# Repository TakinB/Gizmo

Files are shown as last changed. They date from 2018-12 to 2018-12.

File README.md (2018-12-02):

# Deck Tape 

<p align="center">
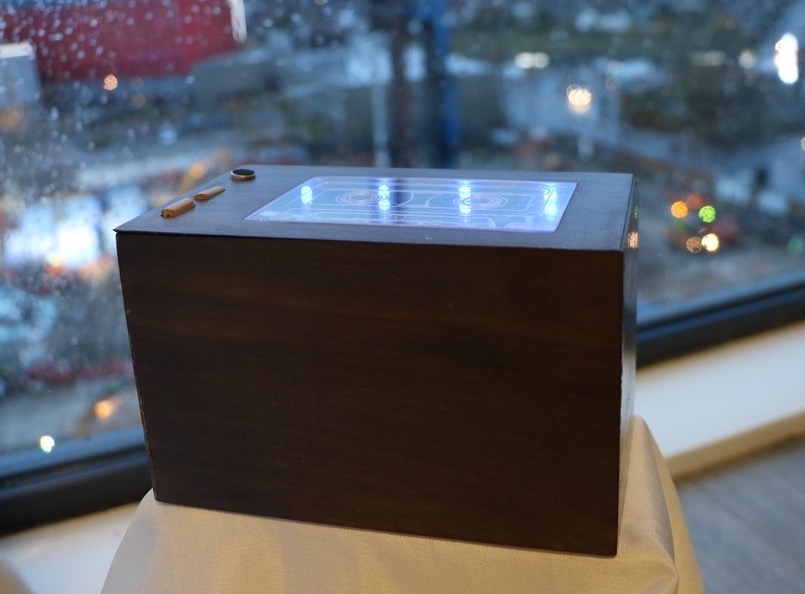
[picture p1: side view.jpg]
  
</p>

Deck Tape is a tribute to cassette players. It's an audio visualizer that integrates sound, color, and touch. 
An Arduino Uno board is used to control LED lights as well as the speed and direction of a DC motor based on the volume of the environment sounds and music.

A magnet is mounted on top of each DC motor which creates patterns in iron filings on the box top surface.

<p align="center">
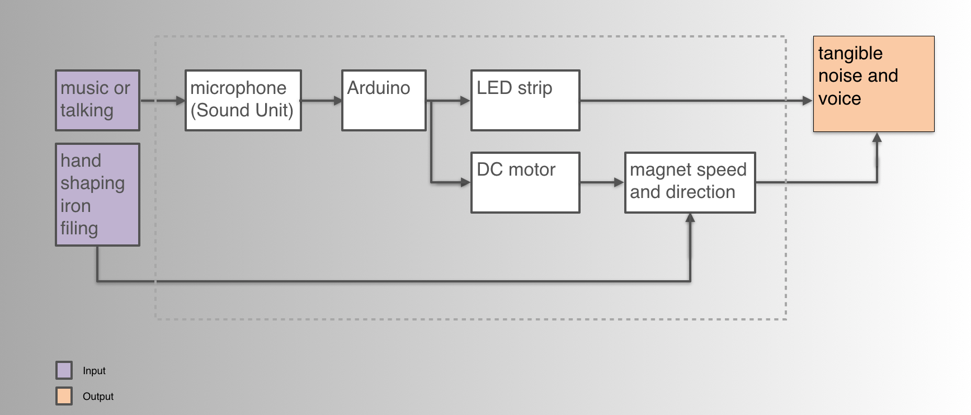
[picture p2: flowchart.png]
  
</p>

**Why magnets?** 
>Cassette players use an electronic magnet to permanently change the orientation of magnetic oxide materials on the cassette tapes.

**Why cassettes?**  
>When I look back, I remember every cassette tape that I owned and my emotions when listening to them. However, it wasn't the case with my digital album collections. So I started with the question of: How can we bring the physical interaction that we had with cassette tapes into the modern way of listening to music?

In order to recreate the physical interaction with a cassette player, push buttons in Deck Tape is made with the same metallic latches that cassette players use. In other words, when you press buttons, you'll hear the same nostalgic click of old cassette players.
Also, users can change the patterns being shaped by the magnet by playing with the iron filings. In addition, LED colors and intensities change based on the historical volume of the song.

<p align="center">
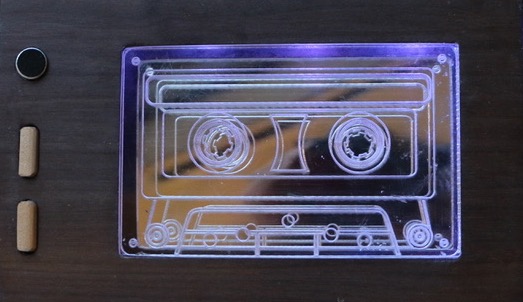
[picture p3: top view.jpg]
  
</p>

## Getting Started
**Hardware:**
You will need the following in order to build the hardware:

 1. ring magnets (2) 
 2. DC motors (2)
 3. mirror acrylic 
 4. clear acrylic 
 5. walnut tree wood sheet
 6.  sound unit 
 7. Arduino Uno 
 8. power supply 
 9. LED strip Neo Pixel 
 10. L293D motor driver

**Software:**
You will need the following libraries installed for Arduino:
[Adafruit's NeoPixel library](https://github.com/adafruit/Adafruit_NeoPixel)

## Schematics
Please refer to the schematics folder on how to wire up the board with motors, sound module, and LED strip.

## Licenses

 - Bahareh Saboktakin, Royal College of Art, 27/11/2018
 - SparkFun Addressable RGB LED Sound and Music Visualizer Tutorial Arduino Code by Michael Bartlett date: 2/7/16 and 27/11/18 license: Creative Commons Attribution-ShareAlike 4.0 (CC BY-SA 4.0)

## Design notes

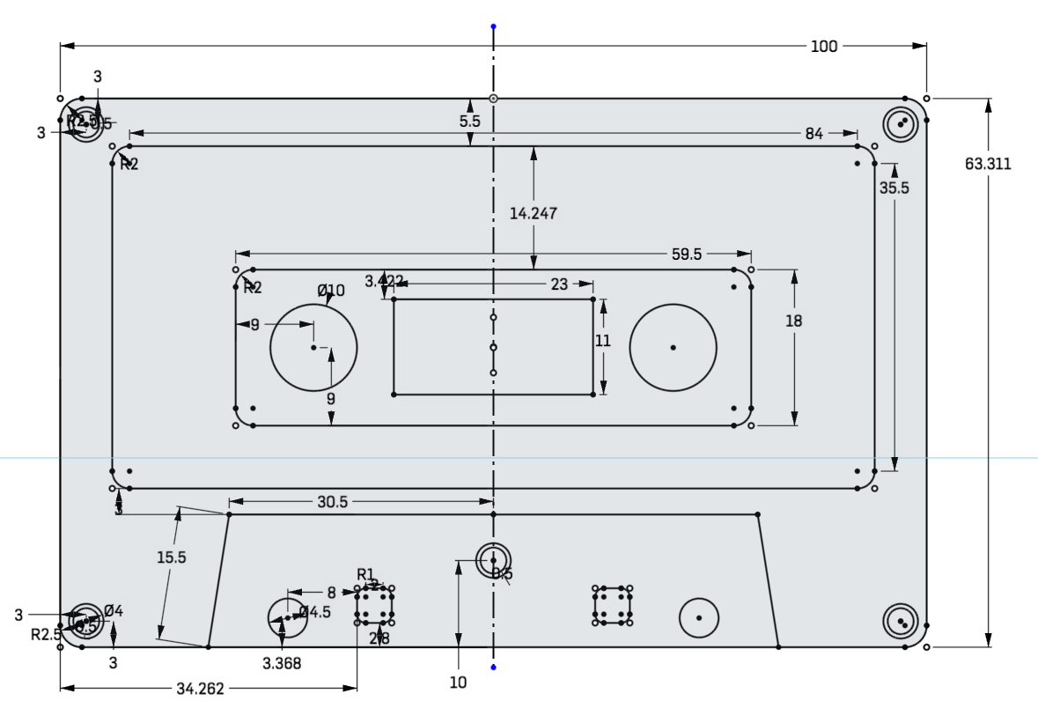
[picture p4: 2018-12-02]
Laser cutter files/cassette tape dimensions.png

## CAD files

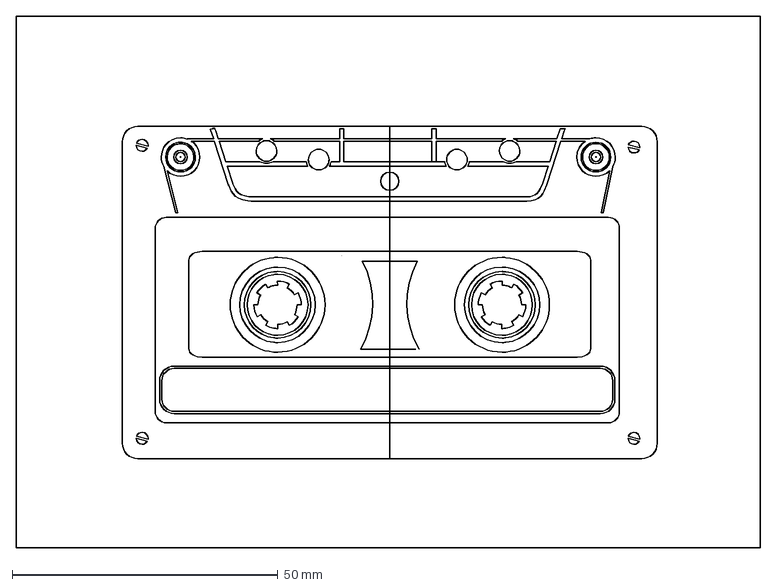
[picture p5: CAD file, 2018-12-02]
Laser cutter files/cassette tape top etching.dxf
140.0 x 100.0 mm

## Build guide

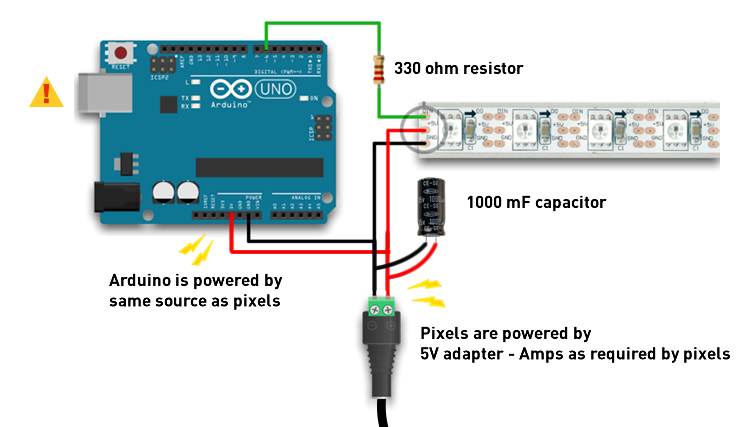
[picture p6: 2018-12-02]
Schematics/LED strip wiring - from adafruit.png

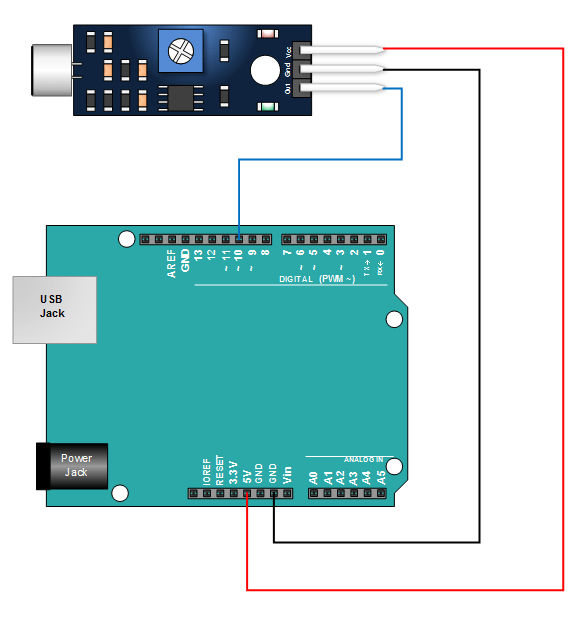
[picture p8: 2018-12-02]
Schematics/sound module wiring - from Henrys bench.png

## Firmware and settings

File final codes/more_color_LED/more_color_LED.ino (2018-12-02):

/* SparkFun Addressable RGB LED Sound and Music Visualizer Tutorial Arduino Code
 * by: Michael Bartlett
 * and: Bahareh Saboktakin
 * Royal College of Art
 * SparkFun Electronics
 * date: 2/7/16 and 27/11/18
 * license: Creative Commons Attribution-ShareAlike 4.0 (CC BY-SA 4.0)
 * Do whatever you'd like with this code, use it for any purpose.
 * Please attribute and keep this license.
*/

//Libraries
#include <Adafruit_NeoPixel.h>  //Library to simplify interacting with the LED strand
#ifdef __AVR__
#include <avr/power.h>   //Includes the library for power reduction registers if your chip supports them. 
#endif                   //More info: http://www.nongnu.org/avr-libc/user-manual/group__avr__power.htlm


//Constants (change these as necessary)
#define LED_PIN    7 //Pin for the pixel strand. Can be analog or digital.
#define LED_TOTAL 20  //Change this to the number of LEDs in your strand.
#define LED_HALF  LED_TOTAL/2
#define VISUALS   6   //Change this accordingly if you add/remove a visual in the switch-case in Visualize()

#define AUDIO_PIN A0  //Pin for the envelope of the sound detector
#define KNOB_PIN  A1  //Pin for the trimpot 10K

//DC Motor 1
#define ENABLE1 5
#define DIRA1 3
#define DIRB1 4

//DC Motor 2
#define ENABLE2 10
#define DIRA2 8
#define DIRB2 9

//////////<Globals>
//  These values either need to be remembered from the last pass of loop() or
//  need to be accessed by several functions in one pass, so they need to be global.

Adafruit_NeoPixel strand = Adafruit_NeoPixel(LED_TOTAL, LED_PIN, NEO_GRB + NEO_KHZ800);  //LED strand objects

uint16_t gradient = 0; //Used to iterate and loop through each color palette gradually

//IMPORTANT:
//  This array holds the "threshold" of each color function (i.e. the largest number they take before repeating).
//  The values are in the same order as in ColorPalette()'s switch case (Rainbow() is first, etc). This is simply to
//  keep "gradient" from overflowing, the color functions themselves can take any positive value. For example, the
//  largest value Rainbow() takes before looping is 1529, so "gradient" should reset after 1529, as listed.
//     Make sure you add/remove values accordingly if you add/remove a color function in the switch-case in ColorPalette().

uint16_t thresholds[] = {1529, 1019, 764, 764, 764, 1274};

uint8_t palette = 0;  //Holds the current color palette.
uint8_t visual = 0;   //Holds the current visual being displayed.
uint8_t volume = 0;   //Holds the volume level read from the sound detector.
uint8_t last = 0;     //Holds the value of volume from the previous loop() pass.

float maxVol = 200;    //Holds the largest volume recorded thus far to proportionally adjust the visual's responsiveness.
float knob = 1023.0;  //Holds the percentage of how twisted the trimpot is. Used for adjusting the max brightness.
float avgBump = 0;    //Holds the "average" volume-change to trigger a "bump."
float avgVol = 0;     //Holds the "average" volume-level to proportionally adjust the visual experience.
float shuffleTime = 0;  //Holds how many seconds of runtime ago the last shuffle was (if shuffle mode is on).

////////////////////////////////////////////////////////////////////////////////////////////////////////////////
//NOTE: The reason "average" is quoted is because it is not a true mathematical average. This is because I have
//      found what I call a "sequenced average" is more successful in execution than a real average. The difference
//      is that the sequenced average doesn't use the pool of all values recorded thus far, but rather averages the
//      last average and the current value received (in sequence). Concretely:
//
//          True average: (1 + 2 + 3) / 3 = 2
//          Sequenced: (1 + 2) / 2 = 1.5 --> (1.5 + 3) / 2 = 2.25  (if 1, 2, 3 was the order the values were received)
//
//      All "averages" in the program operate this way. The difference is subtle, but the reason is that sequenced
//      averages are more adaptive to changes in the overall volume. In other words, if you went from loud to quiet,
//      the sequenced average is more likely to show an accurate and proportional adjustment more fluently.
////////////////////////////////////////////////////////////////////////////////////////////////////////////////

bool shuffle = false;  //Toggles shuffle mode.
bool bump = false;     //Used to pass if there was a "bump" in volume

//For Traffic() visual
int8_t pos[LED_TOTAL] = { -2};    //Stores a population of color "dots" to iterate across the LED strand.
uint8_t rgb[LED_TOTAL][3] = {0};  //Stores each dot's specific RGB values.

//For Snake() visual
bool left = false;  //Determines the direction of iteration. Recycled in PaletteDance()
int8_t dotPos = 0;  //Holds which LED in the strand the dot is positioned at. Recycled in most other visuals.
float timeBump = 0; //Holds the time (in runtime seconds) the last "bump" occurred.
float avgTime = 0;  //Holds the "average" amount of time between each "bump" (used for pacing the dot's movement).

//Motor Control variables
int maxDirTime = 1000; //Maximum delay time that motor rotates in same direction
int motor_dir_counter = 0;

//////////</Globals>


//////////<Standard Functions>

void setup() {    //Like it's named, this gets ran before any other function.

  //pinMode(A0,INPUT_PULLUP); //added initially for creating a switch from cassette player push buttons.

  pinMode(ENABLE1,OUTPUT);
  pinMode(DIRA1,OUTPUT);
  pinMode(DIRB1,OUTPUT);

  pinMode(ENABLE2,OUTPUT);
  pinMode(DIRA2,OUTPUT);
  pinMode(DIRB2,OUTPUT);
  
  Serial.begin(9600); //Sets data rate for serial data transmission.

  //Defines the buttons pins to be input.
  pinMode(BUTTON_1, INPUT); pinMode(BUTTON_2, INPUT); pinMode(BUTTON_3, INPUT);

  //Write a "HIGH" value to the button pins.
  digitalWrite(BUTTON_1, HIGH); digitalWrite(BUTTON_2, HIGH); digitalWrite(BUTTON_3, HIGH);

  strand.begin(); //Initialize the LED strand object.
  strand.show();  //Show a blank strand, just to get the LED's ready for use.
}


void loop() {  //This is where the magic happens. This loop produces each frame of the visual.

  volume = analogRead(AUDIO_PIN);       //Record the volume level from the sound detector
  knob = analogRead(KNOB_PIN) / 1023.0; //Record how far the trimpot is twisted
  
  // if (!  digitalRead(A0)){ // If switch is ON (cassette player play button is pressed) go ahead with LED lighting and pwm for controling motor
  
  //Sets a threshold for volume.
  //  In practice I've found noise can get up to 15, so if it's lower, the visual thinks it's silent.
  //  Also if the volume is less than average volume / 2 (essentially an average with 0), it's considered silent.
  if (volume < avgVol / 2.0 || volume < 15) volume = 0;

  else avgVol = (avgVol + volume) / 2.0; //If non-zeo, take an "average" of volumes.

  //If the current volume is larger than the loudest value recorded, overwrite
  if (volume > maxVol) maxVol = volume;

  //Check the Cycle* functions for specific instructions if you didn't include buttons in your design.
  ////////////////////////////////////////////////////////////////////////////////////////////////////
  CyclePalette();  //Changes palette for shuffle mode or button press.

  CycleVisual();   //Changes visualization for shuffle mode or button press.
  ////////////////////////////////////////////////////////////////////////////////////////////////////

  //This is where "gradient" is modulated to prevent overflow.
  if (gradient > thresholds[palette]) {
    gradient %= thresholds[palette] + 1;

    //Everytime a palette gets completed is a good time to readjust "maxVol," just in case
    //  the song gets quieter; we also don't want to lose brightness intensity permanently
    //  because of one stray loud sound.
    maxVol = (maxVol + volume) / 2.0;
  }

  //If there is a decent change in volume since the last pass, average it into "avgBump"
  if (volume - last > 10) avgBump = (avgBump + (volume - last)) / 2.0;

  //If there is a notable change in volume, trigger a "bump"
  //  avgbump is lowered just a little for comparing to make the visual slightly more sensitive to a beat.
  bump = (volume - last > avgBump * .9);  

  //If a "bump" is triggered, average the time between bumps
  if (bump) {
    avgTime = (((millis() / 1000.0) - timeBump) + avgTime) / 2.0;
    timeBump = millis() / 1000.0;
  }

  //Debugging serial prints
  Serial.println("max volume");
  Serial.println(maxVol);

  Serial.println("Mic value");
  Serial.println(volume);
  
  Visualize();   //Calls the appropriate visualization to be displayed with the globals as they are.

  ControlMotor();  //Controls directions of the DC motor based on whether we had a bump in the volume.
  
  gradient++;    //Increments gradient

  last = volume; //Records current volume for next pass

  delay(30);     //Paces visuals so they aren't too fast to be enjoyable
//}
  //else{ // Do this if the cassette player stop push button is pressed (switch off)
    //   digitalWrite(ENABLE1,0); //enable on
      // digitalWrite(ENABLE2,0); //enable on
    //}
}
//////////</Standard Functions>


//////////<Visual Functions>

//This function calls the appropriate visualization based on the value of "visual"
void Visualize() {
  switch (visual) {
    case 0: return Pulse();
    case 1: return PalettePulse();
    case 2: return Traffic();
    case 3: return Snake();
    case 4: return PaletteDance();
    case 5: return Glitter();
    case 6: return Paintball();
    default: return Pulse();
  }
}

//////////////////////////////////////////////////////////////////////////////////////////////////////////
//NOTE: The strand displays RGB values as a 32 bit unsigned integer (uint32_t), which is why ColorPalette()
//      and all associated color functions' return types are uint32_t. This value is a composite of 3
//      unsigned 8bit integer (uint8_t) values (0-255 for each of red, blue, and green). You'll notice the
//      function split() (listed below) is used to dissect these 8bit values from the 32-bit color value.
//////////////////////////////////////////////////////////////////////////////////////////////////////////


//This function calls the appropriate color palette based on "palette"
//  If a negative value is passed, returns the appropriate palette withe "gradient" passed.
//  Otherwise returns the color palette with the passed value (useful for fitting a whole palette on the strand).
uint32_t ColorPalette(float num) {
  switch (palette) {
    case 0: return (num < 0) ? Rainbow(gradient) : Rainbow(num);
    case 1: return (num < 0) ? Sunset(gradient) : Sunset(num);
    case 2: return (num < 0) ? Ocean(gradient) : Ocean(num);
    case 3: return (num < 0) ? PinaColada(gradient) : PinaColada(num);
    case 4: return (num < 0) ? Sulfur(gradient) : Sulfur(num);
    case 5: return (num < 0) ? NoGreen(gradient) : NoGreen(num);
    default: return Rainbow(gradient);
  }
}

///////////////////////////////////////////////////////////////////////////////////////////////////////////////
//NOTE: All of these visualizations feature some aspect that affects brightness based on the volume relative to
//      maxVol, so that louder = brighter. Initially, I did simple proportions (volume/maxvol), but I found this
//      to be visually indistinct. I then tried an exponential method (raising the value to the power of
//      volume/maxvol). While this was more visually satisfying, I've opted for a balance between the two. You'll
//      notice something like pow(volume/maxVol, 2.0) in the functions below. This simply squares the ratio of
//      volume to maxVol to get a more exponential curve, but not as exaggerated as an actual exponential curve.
//      In essence, this makes louder volumes brighter, and lower volumes dimmer, to be more visually distinct.
///////////////////////////////////////////////////////////////////////////////////////////////////////////////


//PULSE
//Pulse from center of the strand
void Pulse() {

  fade(0.75);   //Listed below, this function simply dims the colors a little bit each pass of loop()

  //Advances the palette to the next noticeable color if there is a "bump"
  if (bump) gradient += thresholds[palette] / 24;

  //If it's silent, we want the fade effect to take over, hence this if-statement
  if (volume > 0) {
    uint32_t col = ColorPalette(-1); //Our retrieved 32-bit color

    //These variables determine where to start and end the pulse since it starts from the middle of the strand.
    //  The quantities are stored in variables so they only have to be computed once (plus we use them in the loop).
    int start = LED_HALF - (LED_HALF * (volume / maxVol));
    int finish = LED_HALF + (LED_HALF * (volume / maxVol)) + strand.numPixels() % 2;
    //Listed above, LED_HALF is simply half the number of LEDs on your strand. ↑ this part adjusts for an odd quantity.

    for (int i = start; i < finish; i++) {

      //"damp" creates the fade effect of being dimmer the farther the pixel is from the center of the strand.
      //  It returns a value between 0 and 1 that peaks at 1 at the center of the strand and 0 at the ends.
      float damp = sin((i - start) * PI / float(finish - start));

      //Squaring damp creates more distinctive brightness.
      damp = pow(damp, 2.0);

      //Fetch the color at the current pixel so we can see if it's dim enough to overwrite.
      uint32_t col2 = strand.getPixelColor(i);

      //Takes advantage of one for loop to do the following:
      // Appropriatley adjust the brightness of this pixel using location, volume, and "knob"
      // Take the average RGB value of the intended color and the existing color, for comparison
      uint8_t colors[3];
      float avgCol = 0, avgCol2 = 0;
      for (int k = 0; k < 3; k++) {
        colors[k] = split(col, k) * damp * knob * pow(volume / maxVol, 2);
        avgCol += colors[k];
        avgCol2 += split(col2, k);
      }
      avgCol /= 3.0, avgCol2 /= 3.0;

      //Compare the average colors as "brightness". Only overwrite dim colors so the fade effect is more apparent.
      if (avgCol > avgCol2) strand.setPixelColor(i, strand.Color(colors[0], colors[1], colors[2]));
    }
  }
  //This command actually shows the lights. If you make a new visualization, don't forget this!
  strand.show();
}


//PALETTEPULSE
//Same as Pulse(), but colored the entire pallet instead of one solid color
void PalettePulse() {
  fade(0.75);
  if (bump) gradient += thresholds[palette] / 24;
  if (volume > 0) {
    int start = LED_HALF - (LED_HALF * (volume / maxVol));
    int finish = LED_HALF + (LED_HALF * (volume / maxVol)) + strand.numPixels() % 2;
    for (int i = start; i < finish; i++) {
      float damp = sin((i - start) * PI / float(finish - start));
      damp = pow(damp, 2.0);

      //This is the only difference from Pulse(). The color for each pixel isn't the same, but rather the
      //  entire gradient fitted to the spread of the pulse, with some shifting from "gradient".
      int val = thresholds[palette] * (i - start) / (finish - start);
      val += gradient;
      uint32_t col = ColorPalette(val);

      uint32_t col2 = strand.getPixelColor(i);
      uint8_t colors[3];
      float avgCol = 0, avgCol2 = 0;
      for (int k = 0; k < 3; k++) {
        colors[k] = split(col, k) * damp * knob * pow(volume / maxVol, 2);
        avgCol += colors[k];
        avgCol2 += split(col2, k);
      }
      avgCol /= 3.0, avgCol2 /= 3.0;
      if (avgCol > avgCol2) strand.setPixelColor(i, strand.Color(colors[0], colors[1], colors[2]));
    }
  }
  strand.show();
}


//TRAFFIC
//Dots racing into each other
void Traffic() {

  //fade() actually creates the trail behind each dot here, so it's important to include.
  fade(0.8);

  //Create a dot to be displayed if a bump is detected.
  if (bump) {

    //This mess simply checks if there is an open position (-2) in the pos[] array.
    int8_t slot = 0;
    for (slot; slot < sizeof(pos); slot++) {
      if (pos[slot] < -1) break;
      else if (slot + 1 >= sizeof(pos)) {
        slot = -3;
        break;
      }
    }

    //If there is an open slot, set it to an initial position on the strand.
    if (slot != -3) {

      //Evens go right, odds go left, so evens start at 0, odds at the largest position.
      pos[slot] = (slot % 2 == 0) ? -1 : strand.numPixels();

      //Give it a color based on the value of "gradient" during its birth.
      uint32_t col = ColorPalette(-1);
      gradient += thresholds[palette] / 24;
      for (int j = 0; j < 3; j++) {
        rgb[slot][j] = split(col, j);
      }
    }
  }

  //Again, if it's silent we want the colors to fade out.
  if (volume > 0) {

    //If there's sound, iterate each dot appropriately along the strand.
    for (int i = 0; i < sizeof(pos); i++) {

      //If a dot is -2, that means it's an open slot for another dot to take over eventually.
      if (pos[i] < -1) continue;

      //As above, evens go right (+1) and odds go left (-1)
      pos[i] += (i % 2) ? -1 : 1;

      //Odds will reach -2 by subtraction, but if an even dot goes beyond the LED strip, it'll be purged.
      if (pos[i] >= strand.numPixels()) pos[i] = -2;

      //Set the dot to its new position and respective color.
      //  I's old position's color will gradually fade out due to fade(), leaving a trail behind it.
      strand.setPixelColor( pos[i], strand.Color(
                              float(rgb[i][0]) * pow(volume / maxVol, 2.0) * knob,
                              float(rgb[i][1]) * pow(volume / maxVol, 2.0) * knob,
                              float(rgb[i][2]) * pow(volume / maxVol, 2.0) * knob)
                          );
    }
  }
  strand.show(); //Again, don't forget to actually show the lights!
}


//SNAKE
//Dot sweeping back and forth to the beat
void Snake() {
  if (bump) {

    //Change color a little on a bump
    gradient += thresholds[palette] / 30;

    //Change the direction the dot is going to create the illusion of "dancing."
    left = !left;
  }

  fade(0.975); //Leave a trail behind the dot.

  uint32_t col = ColorPalette(-1); //Get the color at current "gradient."

  //The dot should only be moved if there's sound happening.
  //  Otherwise if noise starts and it's been moving, it'll appear to teleport.
  if (volume > 0) {

    //Sets the dot to appropriate color and intensity
    strand.setPixelColor(dotPos, strand.Color(
                           float(split(col, 0)) * pow(volume / maxVol, 1.5) * knob,
                           float(split(col, 1)) * pow(volume / maxVol, 1.5) * knob,
                           float(split(col, 2)) * pow(volume / maxVol, 1.5) * knob)
                        );

    //This is where "avgTime" comes into play.
    //  That variable is the "average" amount of time between each "bump" detected.
    //  So we can use that to determine how quickly the dot should move so it matches the tempo of the music.
    //  The dot moving at normal loop speed is pretty quick, so it's the max speed if avgTime < 0.15 seconds.
    //  Slowing it down causes the color to update, but only change position every other amount of loops.
    if (avgTime < 0.15)                                               dotPos += (left) ? -1 : 1;
    else if (avgTime >= 0.15 && avgTime < 0.5 && gradient % 2 == 0)   dotPos += (left) ? -1 : 1;
    else if (avgTime >= 0.5 && avgTime < 1.0 && gradient % 3 == 0)    dotPos += (left) ? -1 : 1;
    else if (gradient % 4 == 0)                                       dotPos += (left) ? -1 : 1;
  }

  strand.show(); // Display the lights

  //Check if dot position is out of bounds.
  if (dotPos < 0)    dotPos = strand.numPixels() - 1;
  else if (dotPos >= strand.numPixels())  dotPos = 0;
}
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

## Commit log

2018-11-22 Interim review codes - servo and LED strip work
2018-11-27 Changed core logic for LED lighting and revert back to DC motor
    [more_color_LED.ino]
2018-11-29 pins for LED and mic corrected
    [more_color_LED.ino]
2018-12-02 Added photos and dxf files for laser cutting
    [cassette tape top etching.dxf]
2018-12-02 added schematics
2018-12-02 Added flowchart and centered images
2018-12-02 Added flowchart and corrected image alignment
2018-12-02 added flowchart image as it doesn't support mermaid
